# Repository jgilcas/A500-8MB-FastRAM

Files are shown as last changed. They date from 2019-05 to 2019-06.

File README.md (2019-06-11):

# A500-8MB-FastRAM

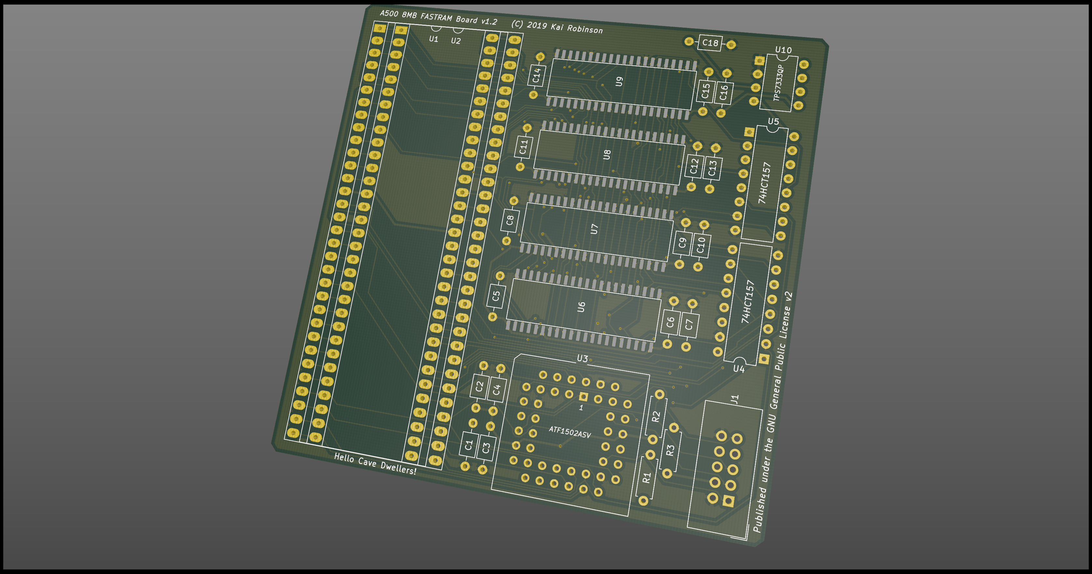
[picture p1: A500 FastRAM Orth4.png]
A500 8MB FastRAM Board


8MB FastRAM Board for the Amiga 500 &amp; Amiga 500+

This board is based on the A600 8MB FastRAM board here: http://lvd.nedopc.com/Projects/a600_8mb/index.html

As such, the schematic is a derivative/fork of the original design, to accommodate it's usage in A500's (might also work in A1000's & A2000's).

Everything has been designed to be as easy to solder as possible, minimal surface mount, with the exception of the memory modules, but they're SOJ-42, which should be easy enough even with a basic soldering iron.

The code for the CPLD has been mostly unchanged from the original, just a single letter changed to reflect usage in the A500 as opposed to the A600, along with renaming the signal pins to something simpler.

There is only 16 Mb of addressable space on 68000 CPU. This board uses half of that space, residing at $200000-$9FFFFF address range. It does autoconfigure, so no need to do anything in the DOS shell.

The original design used an Altera EPM7032 5v CPLD - this has been changed for an Atmel ATF1502ASV - as these are pin-compatible replacements. 

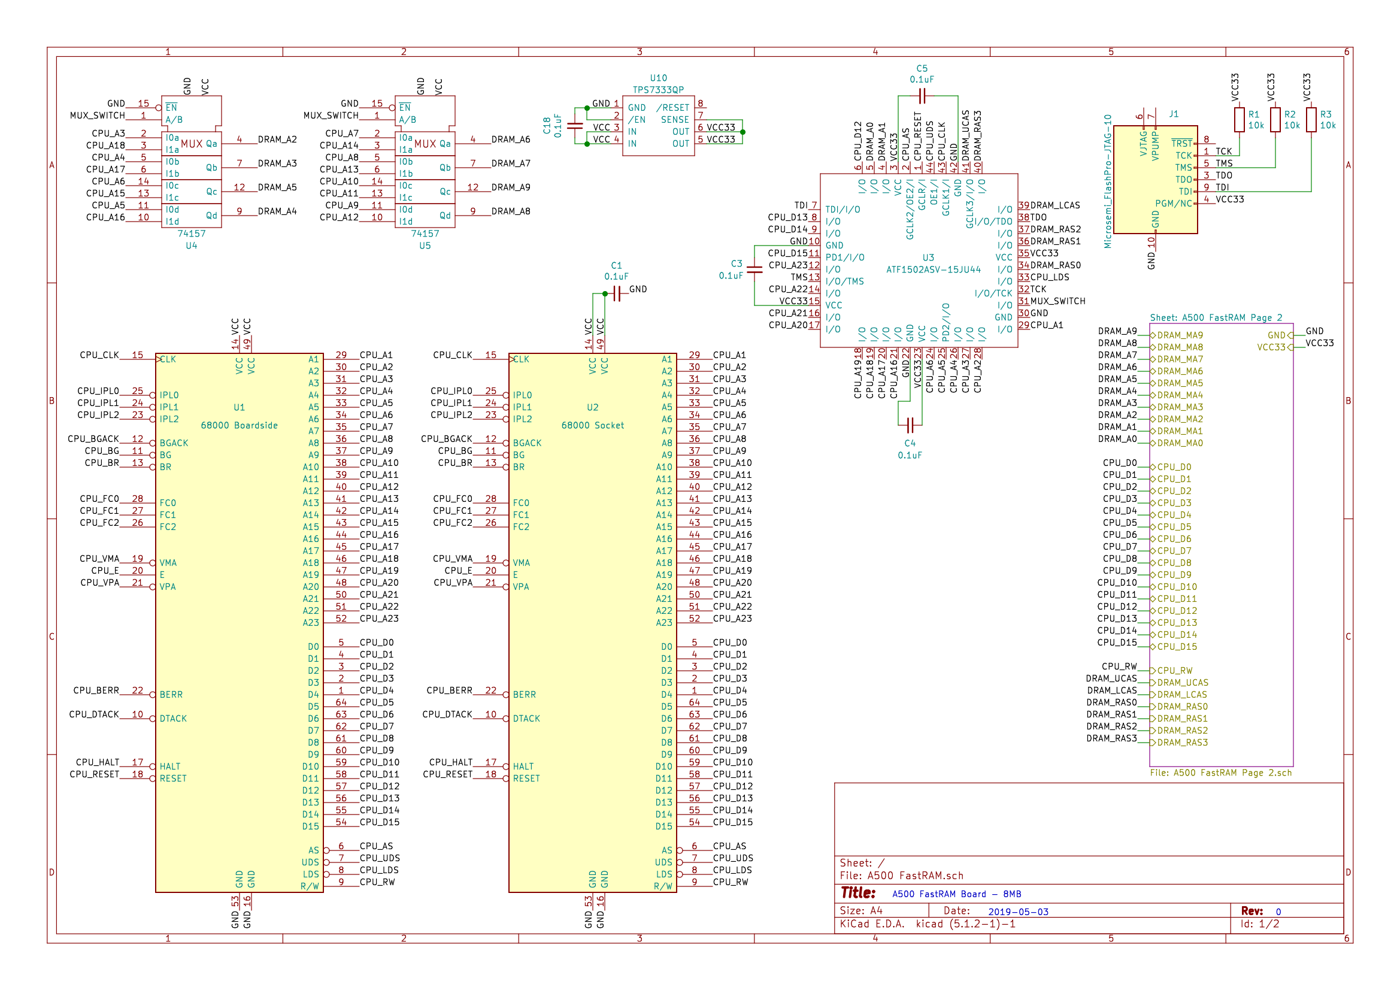
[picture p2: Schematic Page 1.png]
A500 8MB FastRAM Board - Schematic Page 1


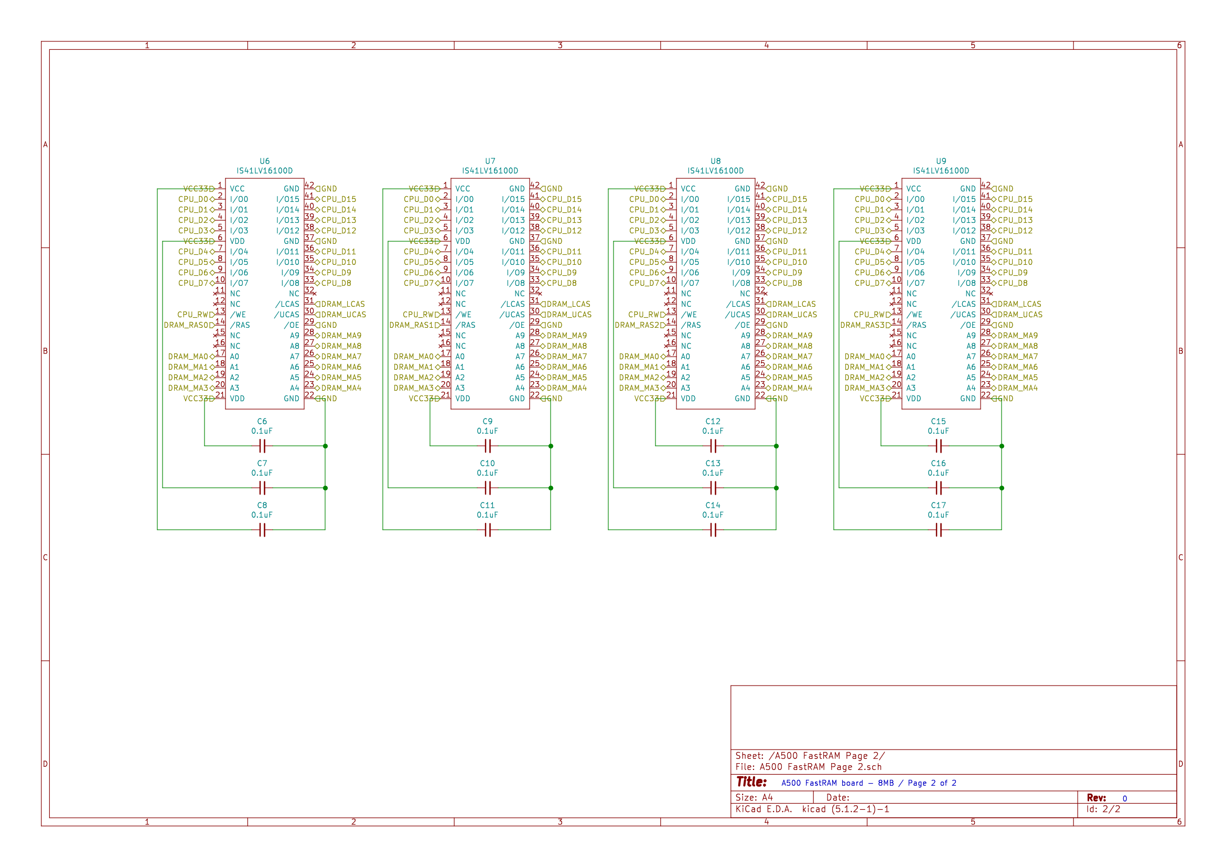
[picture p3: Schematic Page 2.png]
A500 8MB FastRAM Board - Schematic Page 2


# Bill of Materials

1 x TI TPS7333QP - https://www.mouser.co.uk/ProductDetail/Texas-Instruments/TPS7333QP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

2 x 74AHCT157N - https://www.mouser.co.uk/ProductDetail/Texas-Instruments/SN74AHCT157N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

4 x ISSI IS41LV6100D-50KLI - https://www.mouser.co.uk/ProductDetail/ISSI/IS41LV16100D-50KLI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

1 x Microchip ATF1502ASV-15JU44 - https://www.digikey.co.uk/product-detail/en/microchip-technology/ATF1502ASV-15JU44/ATF1502ASV-15JU44-ND/1008571

18 x 0.1uF X7R MLCC Capacitors - https://www.mouser.co.uk/ProductDetail/Vishay/A104M15X7RF5TAA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

3 x 10k Metal Film Resistors - https://www.mouser.co.uk/ProductDetail/Yageo/MFR-25FRF52-10K?qs=sGAEpiMZZMu61qfTUdNhGztMfEiwFKKTpKeEBKehEYg%3D

1 x DIP-8 Socket - https://www.mouser.co.uk/ProductDetail/Mill-Max/115-47-308-41-001000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

2 x DIP-16 Socket - https://www.mouser.co.uk/ProductDetail/Mill-Max/115-47-316-41-001000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

1 x DIP-64 Socket - https://www.mouser.co.uk/ProductDetail/Mill-Max/110-93-964-41-001000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

1 x PLCC-44 Socket - https://www.mouser.co.uk/ProductDetail/Mill-Max/940-44-044-24-000000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

2 x SIL-32 Headers - https://www.mouser.co.uk/ProductDetail/Harwin/M20-9993246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

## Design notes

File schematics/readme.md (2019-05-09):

This project was created in KiCad 5.1.2 - all the files you need to build this project have been added here.

You'll need the custom library files at the very least.

I've included the SPECTRA DSN export from KiCad and the Freerouter Session file as a baseline.

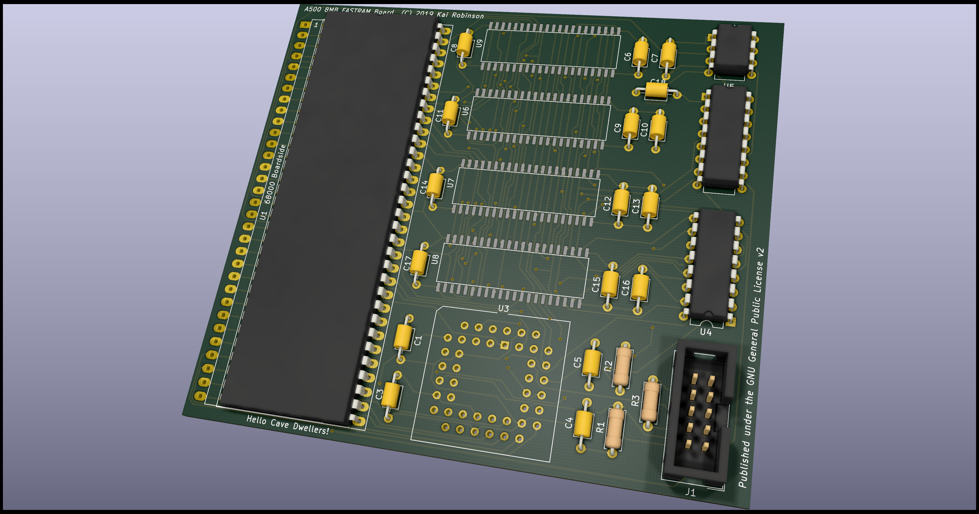
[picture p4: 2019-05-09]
A500 FastRAM Orth1b.png

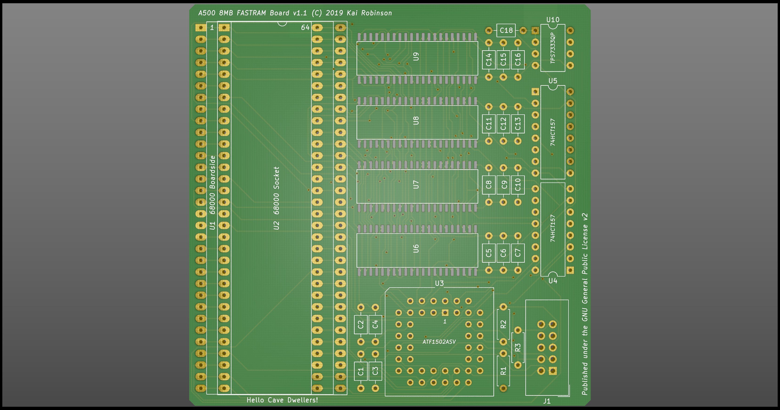
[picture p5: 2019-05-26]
A500 FastRAM Top3.png

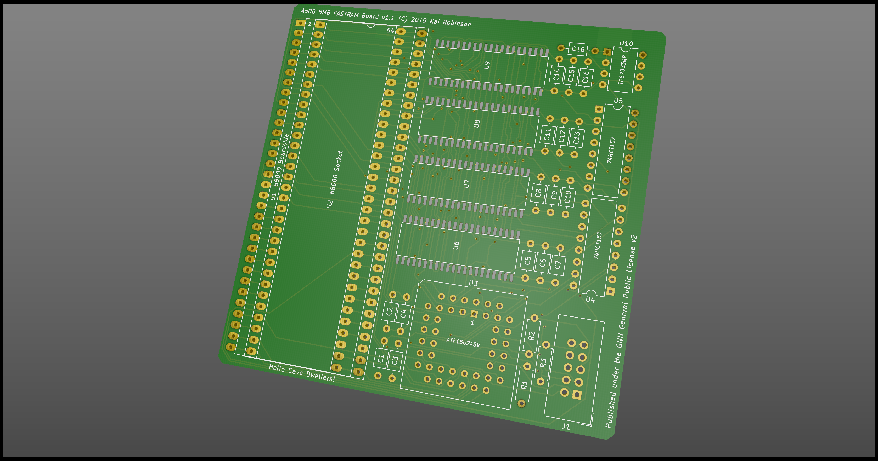
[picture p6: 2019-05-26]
A500 FastRAM Orth2.png

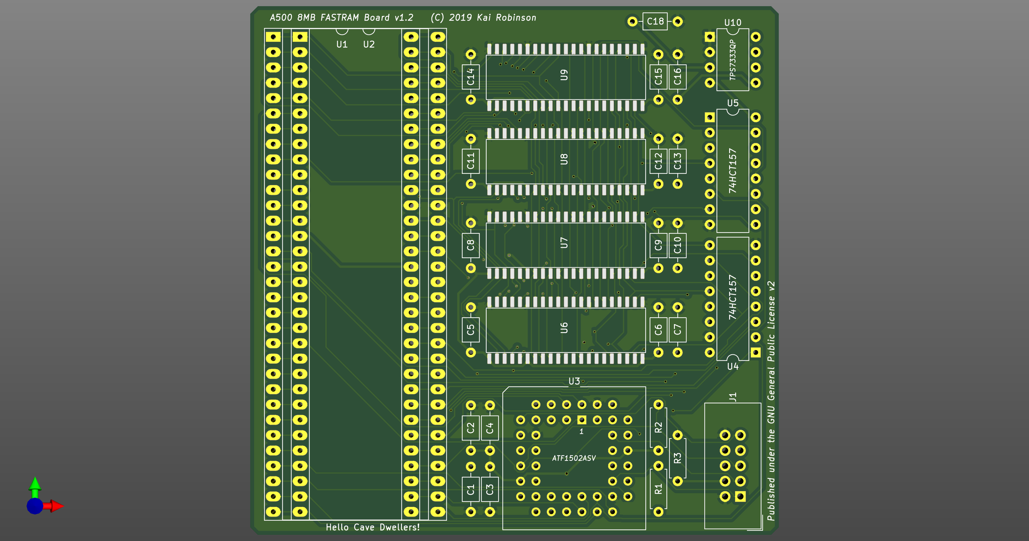
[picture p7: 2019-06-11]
A500 FastRAM Top4.png

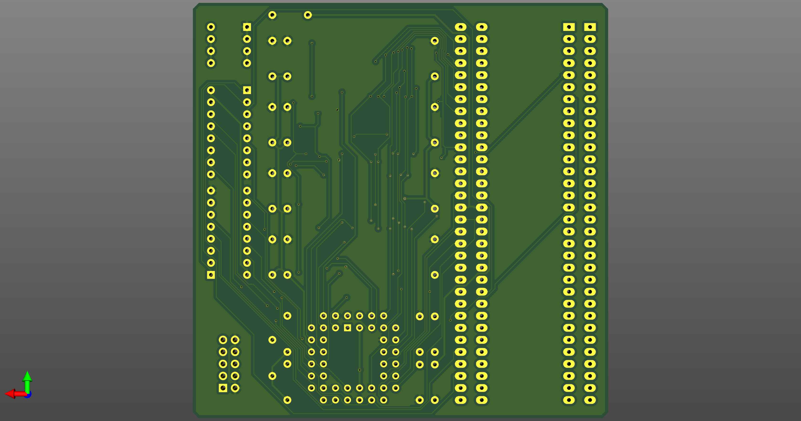
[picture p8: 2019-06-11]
A500 FastRAM Bottom4.png

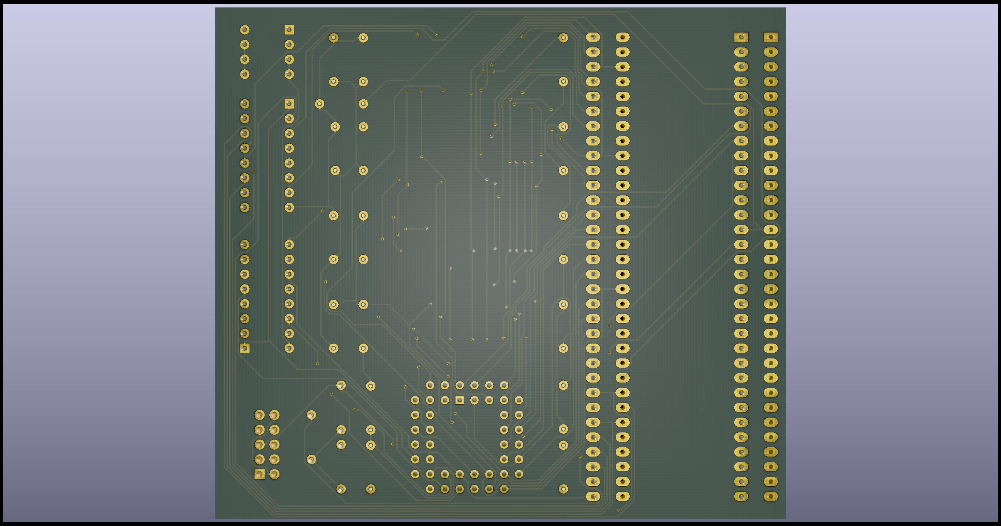
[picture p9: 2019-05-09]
A500 FastRAM Bottom1b.png

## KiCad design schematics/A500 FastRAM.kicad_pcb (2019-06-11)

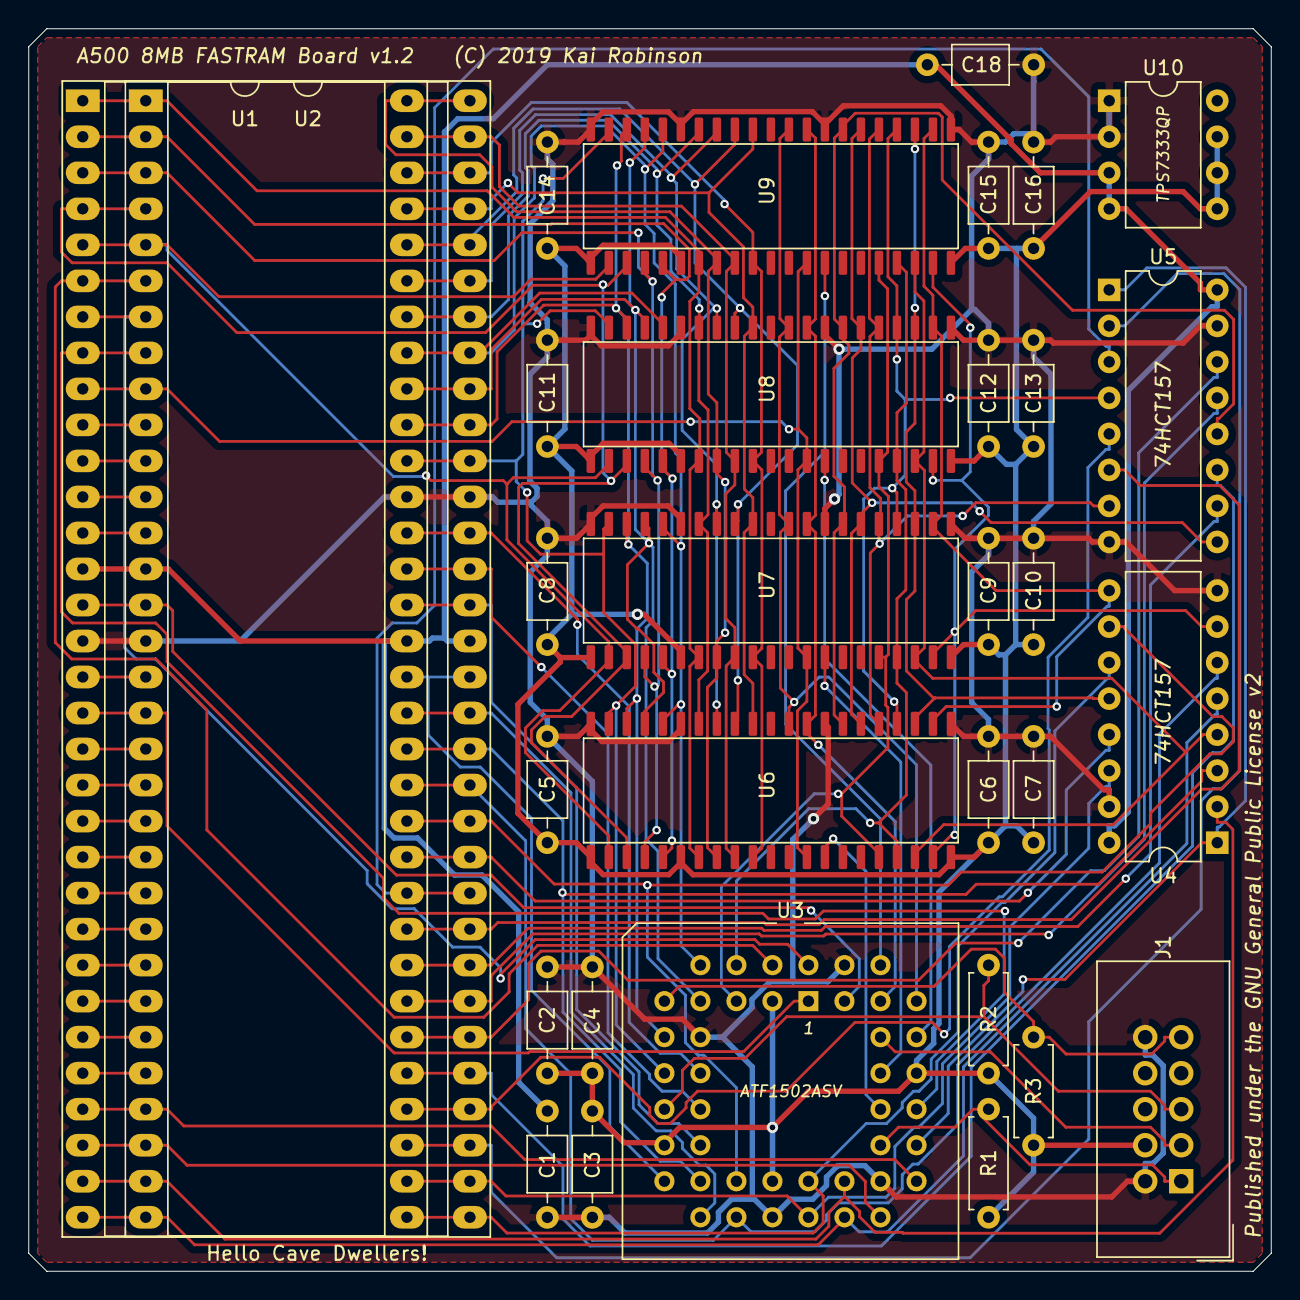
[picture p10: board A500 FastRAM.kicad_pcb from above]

Board: 2 copper layers, 87.6 x 87.6 mm, 31 parts (0 on the bottom side), 84 nets.

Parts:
C1, C2, C3, C4, C5, C6, C7, C8, C9, C10, C11, C12, C13, C14, C15, C16, C18: 0.1uF; C_Axial_L3.8mm_D2.6mm_P7.50mm_Horizontal
J1: Microsemi_FlashPro-JTAG-10; IDC-Header_2x05_P2.54mm_Vertical
R1, R2, R3: 10k; R_Axial_DIN0207_L6.3mm_D2.5mm_P7.62mm_Horizontal
U1: 68000 Boardside; DIP-64_W22.86mm_Socket_LongPads
U2: 68000 Socket; DIP-64_W22.86mm_Socket_LongPads
U3: ATF1502ASV-15JU44; PLCC-44_THT-Socket
U4, U5: 74157; DIP-16_W7.62mm
U6, U7, U8, U9: IS41LV16100D; SOJ-42
U10: TPS7333QP; DIP-8_W7.62mm

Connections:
/CPU_A1: U1.29, U2.29, U3.29
/CPU_A2: U1.30, U2.30, U3.28
/CPU_A3: U1.31, U2.31, U3.27, U4.2
/CPU_A4: U1.32, U2.32, U3.26, U4.5
/CPU_A5: U1.33, U2.33, U3.25, U4.11
/CPU_A6: U1.34, U2.34, U3.24, U4.14
/CPU_A7: U1.35, U2.35, U5.2
/CPU_A8: U1.36, U2.36, U5.5
/CPU_A9: U1.37, U2.37, U5.11
/CPU_A10: U1.38, U2.38, U5.14
/CPU_A11: U1.39, U2.39, U5.13
/CPU_A12: U1.40, U2.40, U5.10
/CPU_A13: U1.41, U2.41, U5.6
/CPU_A14: U1.42, U2.42, U5.3
/CPU_A15: U1.43, U2.43, U4.13
/CPU_A16: U1.44, U2.44, U3.21, U4.10
/CPU_A17: U1.45, U2.45, U3.20, U4.6
/CPU_A18: U1.46, U2.46, U3.19, U4.3
/CPU_A19: U1.47, U2.47, U3.18
/CPU_A20: U1.48, U2.48, U3.17
/CPU_A21: U1.50, U2.50, U3.16
/CPU_A22: U1.51, U2.51, U3.14
/CPU_A23: U1.52, U2.52, U3.12
/CPU_AS: U1.6, U2.6, U3.2
/CPU_BERR: U1.22, U2.22
/CPU_BG: U1.11, U2.11
/CPU_BGACK: U1.12, U2.12
/CPU_BR: U1.13, U2.13
/CPU_CLK: U1.15, U2.15, U3.43
/CPU_D0: U1.5, U2.5, U6.2, U7.2, U8.2, U9.2
/CPU_D1: U1.4, U2.4, U6.3, U7.3, U8.3, U9.3
/CPU_D2: U1.3, U2.3, U6.4, U7.4, U8.4, U9.4
/CPU_D3: U1.2, U2.2, U6.5, U7.5, U8.5, U9.5
/CPU_D4: U1.1, U2.1, U6.7, U7.7, U8.7, U9.7
/CPU_D5: U1.64, U2.64, U6.8, U7.8, U8.8, U9.8
/CPU_D6: U1.63, U2.63, U6.9, U7.9, U8.9, U9.9
/CPU_D7: U1.62, U2.62, U6.10, U7.10, U8.10, U9.10
/CPU_D8: U1.61, U2.61, U6.33, U7.33, U8.33, U9.33
/CPU_D9: U1.60, U2.60, U6.34, U7.34, U8.34, U9.34
/CPU_D10: U1.59, U2.59, U6.35, U7.35, U8.35, U9.35
/CPU_D11: U1.58, U2.58, U6.36, U7.36, U8.36, U9.36
/CPU_D12: U1.57, U2.57, U3.6, U6.38, U7.38, U8.38, U9.38
/CPU_D13: U1.56, U2.56, U3.8, U6.39, U7.39, U8.39, U9.39
/CPU_D14: U1.55, U2.55, U3.9, U6.40, U7.40, U8.40, U9.40
/CPU_D15: U1.54, U2.54, U3.11, U6.41, U7.41, U8.41, U9.41
/CPU_DTACK: U1.10, U2.10
/CPU_E: U1.20, U2.20
/CPU_FC0: U1.28, U2.28
/CPU_FC1: U1.27, U2.27
/CPU_FC2: U1.26, U2.26
/CPU_HALT: U1.17, U2.17
/CPU_IPL0: U1.25, U2.25
/CPU_IPL1: U1.24, U2.24
/CPU_IPL2: U1.23, U2.23
/CPU_LDS: U1.8, U2.8, U3.33
/CPU_RESET: U1.18, U2.18, U3.1
/CPU_RW: U1.9, U2.9, U6.13, U7.13, U8.13, U9.13
/CPU_UDS: U1.7, U2.7, U3.44
/CPU_VMA: U1.19, U2.19
/CPU_VPA: U1.21, U2.21
/DRAM_A0: U3.5, U6.17, U7.17, U8.17, U9.17
/DRAM_A1: U3.4, U6.18, U7.18, U8.18, U9.18
/DRAM_A2: U4.4, U6.19, U7.19, U8.19, U9.19
/DRAM_A3: U4.7, U6.20, U7.20, U8.20, U9.20
/DRAM_A4: U4.9, U6.23, U7.23, U8.23, U9.23
/DRAM_A5: U4.12, U6.24, U7.24, U8.24, U9.24
/DRAM_A6: U5.4, U6.25, U7.25, U8.25, U9.25
/DRAM_A7: U5.7, U6.26, U7.26, U8.26, U9.26
/DRAM_A8: U5.9, U6.27, U7.27, U8.27, U9.27
/DRAM_A9: U5.12, U6.28, U7.28, U8.28, U9.28
/DRAM_LCAS: U3.39, U6.31, U7.31, U8.31, U9.31
/DRAM_RAS0: U3.34, U6.14
/DRAM_RAS1: U3.36, U7.14
/DRAM_RAS2: U3.37, U8.14
/DRAM_RAS3: U3.40, U9.14
/DRAM_UCAS: U3.41, U6.30, U7.30, U8.30, U9.30
/MUX_SWITCH: U3.31, U4.1, U5.1
/TCK: J1.1, R1.2, U3.32
/TDI: J1.9, R3.2, U3.7
/TDO: J1.3, U3.38
/TMS: J1.5, R2.2, U3.13
/VCC33: C2.2, C3.1, C4.2, C5.1, C6.1, C7.1, C8.1, C9.1, C10.1, C11.1, C12.1, C13.1, C14.1, C15.1, C16.1, J1.4, R1.1, R2.1, R3.1, U3.3, U3.15, U3.23, U3.35, U6.1, U6.6, U6.21, U7.1, U7.6, U7.21, U8.1, U8.6, U8.21, U9.1, U9.6, U9.21, U10.5, U10.6, U10.7
GND: C1.2, C2.1, C3.2, C4.1, C5.2, C6.2, C7.2, C8.2, C9.2, C10.2, C11.2, C12.2, C13.2, C14.2, C15.2, C16.2, C18.2, J1.2, J1.10, U1.16, U1.53, U2.16, U2.53, U3.10, U3.22, U3.30, U3.42, U4.8, U4.15, U5.8, U5.15, U6.22, U6.29, U6.37, U6.42, U7.22, U7.29, U7.37, U7.42, U8.22, U8.29, U8.37, U8.42, U9.22, U9.29, U9.37, U9.42, U10.1, U10.2
VCC: C1.1, C18.1, U1.14, U1.49, U2.14, U2.49, U4.16, U5.16, U10.3, U10.4

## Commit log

2019-05-09 Rename A500 FastRAM.sch to schematics/A500 FastRAM.sch
    [A500 FastRAM.sch]
2019-05-09 Rename A500 FastRAM Page 2.sch to schematics/A500 FastRAM Page 2.sch
    [A500 FastRAM Page 2.sch]
2019-05-09 Rename A500 FastRAM.kicad_pcb to schematics/A500 FastRAM.kicad_pcb
    [A500 FastRAM.kicad_pcb]
2019-05-09 Rename A500 FastRAM.pro to schematics/A500 FastRAM.pro
2019-05-09 Rename A500 FastRAM.dsn to schematics/A500 FastRAM.dsn
    [A500 FastRAM.dsn]
2019-05-09 Rename A500 FastRAM.ses to schematics/A500 FastRAM.ses
2019-05-26 Add files via upload
    v1.1 - tweaking layout, compacting things a bit, better routing with less via's
    [A500 FastRAM Page 2.sch, A500 FastRAM.dsn, A500 FastRAM.kicad_pcb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]
2019-06-11 Fixing wrong CPU Socket, tweaking layout & routing
    [A500 FastRAM-B_Cu.gbl, A500 FastRAM-B_Mask.gbs, A500 FastRAM-B_SilkS.gbo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]

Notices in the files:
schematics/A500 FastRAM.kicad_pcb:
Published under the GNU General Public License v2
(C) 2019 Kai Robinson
